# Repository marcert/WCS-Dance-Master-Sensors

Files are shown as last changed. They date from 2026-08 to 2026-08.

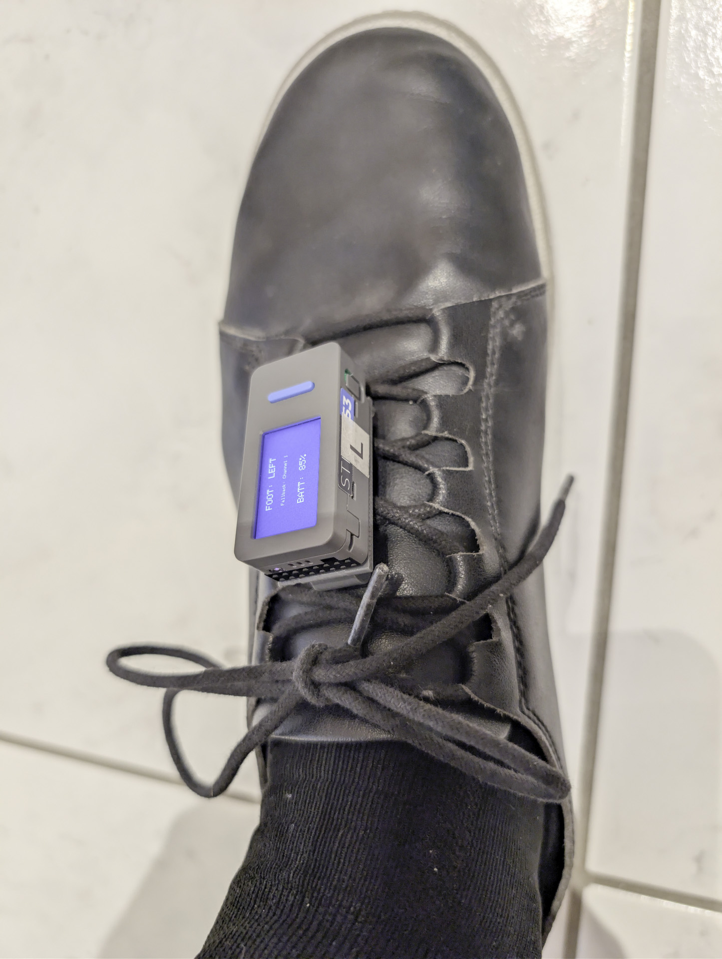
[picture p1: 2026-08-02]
Attachments/Sensor-002.jpg

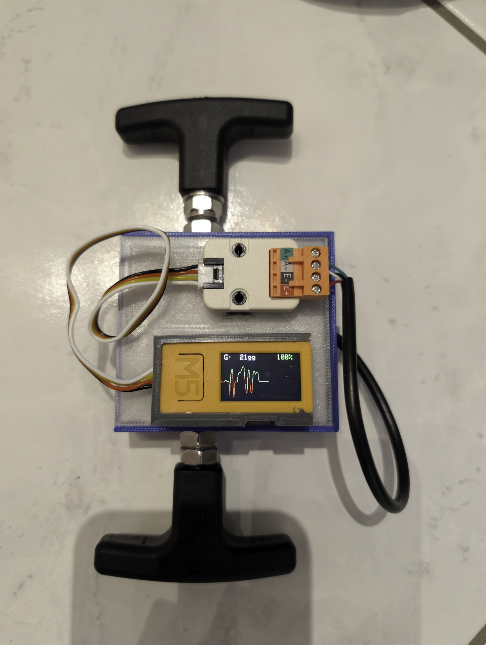
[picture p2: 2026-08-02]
Attachments/Sensor-001.jpg

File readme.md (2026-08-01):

# 🕺 WCS Ultra-Performance Dance & Movement Analysis System

A real-time wireless sensor network and video feedback system built specifically for **West Coast Swing (WCS)** dancers and coaches.

---

## 🎯 Purpose & Goal

Improving connection, timing, and footwork in West Coast Swing often relies on subjective feeling or delayed video review. This system solves that problem by giving **instant physical telemetry and visual feedback** while you dance.

### What it measures in real-time:
* **Footwork & Roll-off Quality (Left & Right Foot):** Measures foot roll-off dynamics via gyroscope angular rate and detects hard impacts / stomping (Z-axis g-force spikes).
* **Connection & Lead/Follow Smoothness (Hand Unit):** Measures pull and push tension in grams via a strain-gauge load cell (-3.5 kg to +3.5 kg) and detects abrupt, harsh movements (jerk index).
* **Live Acoustic & Visual Feedback:** Triggers immediate audio alert tones (e.g., 1000 Hz beep on connection jerk or poor roll-off with heavy impact) and displays synchronized overlay lines directly on a live video feed.

---

## 🚀 Quick Start / How to Use

1. **Power On:** Turn on the **Master Unit** first so it establishes its Wi-Fi channel.
2. **Connect Sensors:** Power on the Foot and Hand sensors. They automatically scan channels (1–13), pair with the Master, and lock onto the channel.
3. **Open Dashboard:** Connect your tablet, phone, or laptop to the Master's Wi-Fi network and open the IP address in any web browser.
4. **Train & Review:**
   * Tap **START CAM** to overlay the telemetry graphs directly over your live camera feed.
   * Use **FREEZE** during or after a pattern to pause graph rendering and analyze connection/footwork spikes frame-by-frame.
   * Press **Button A** on the Hand Unit at any time to tare (zero-out) the weight scale.

---

## 🛠️ Getting Started (Setup & Installation)

### Hardware Requirements
* **1x Master Unit:** M5Stack main unit (M5StickC PLUS / PLUS2 / Core).
* **2x Foot Sensors:** M5Stack units with internal 6-axis IMU.
* **1x Hand Sensor:** M5Stack unit + **HX711** load cell amplifier + Strain-Gauge Load Cell (connected to GPIO 33 DOUT / GPIO 32 SCK).

### Software Requirements
Install the following libraries in Arduino IDE / PlatformIO:
* `M5Unified`
* `WiFi.h` & `esp_wifi.h`
* `esp_now.h`
* `WebServer.h`
* `HX711.h`

### Firmware Flashing
1. **Master Unit:**
   * Create a `secrets.h` file containing your Wi-Fi credentials (`STAMMI_SSID` & `STAMMI_PASS`).
   * Flash the Master code. (If Wi-Fi fails, it falls back to standalone Access Point mode at `192.168.4.1`).
2. **Foot Sensors:**
   * Flash Unit 1 with `#define FOOT_ID 1` (Left Foot).
   * Flash Unit 2 with `#define FOOT_ID 2` (Right Foot).
3. **Hand Sensor:**
   * Flash with `#define HAND_ID 3` (Scale factor default is set to `129.1f`).

---

## 🏗️ System Architecture

```text
                       +-------------------------+
                       |   Foot Sensor (Left)    |
                       | ID: 1 | M5Stack + IMU   |
                       +------------+------------+
                                    |
                                    | (ESP-NOW Broadcast / Channel Auto-Sync)
                                    v
+------------------------+     +----+--------------------+     +-------------------------+
|   Hand / Scale Unit    |---->|   Central Master Unit   |<----|   Foot Sensor (Right)   |
| ID: 3 | HX711 + IMU    |     |    M5Stack Master       |     | ID: 2 | M5Stack + IMU   |
+------------------------+     +----------+--------------+     +-------------------------+
                                          |
                                          | (Wi-Fi AP / STA + WebServer)
                                          v
                              +-----------+--------------+
                              |   Web Dashboard (HTML5)  |
                              | Real-time Canvas Graphs  |
                              | Live Camera Overlay      |
                              +--------------------------+

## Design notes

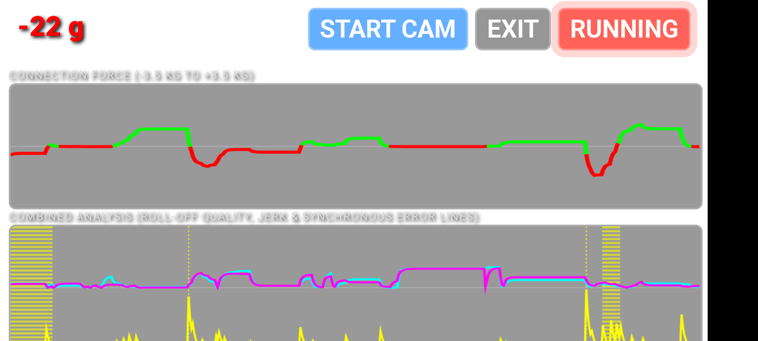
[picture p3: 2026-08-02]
Attachments/screenshot.png

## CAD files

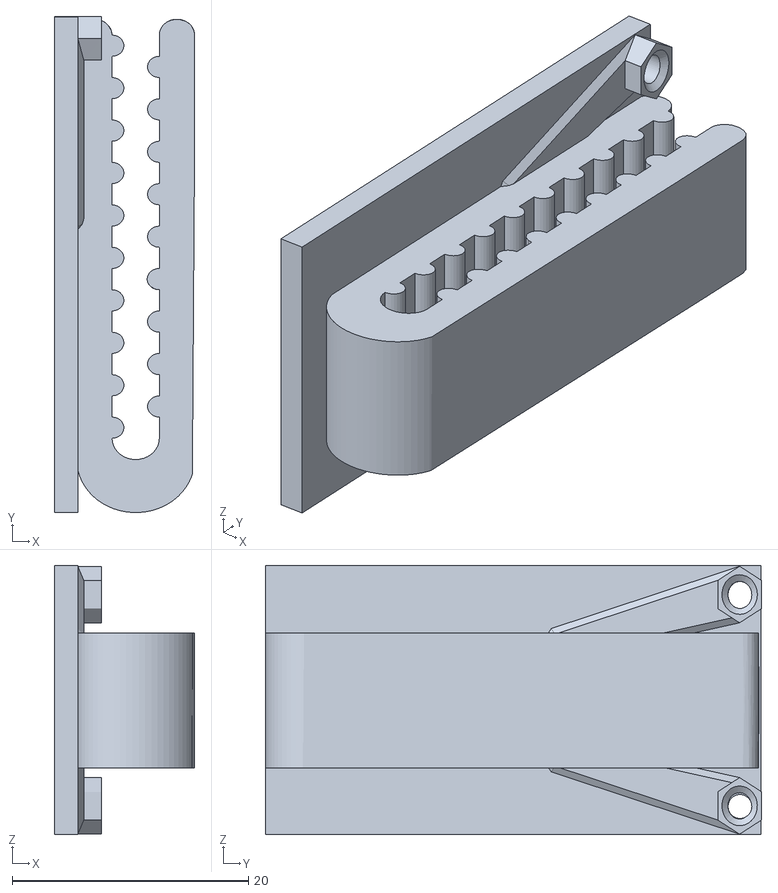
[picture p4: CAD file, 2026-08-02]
Attachments/M5-shoe-mount.stl
11.9 x 42.0 x 22.8

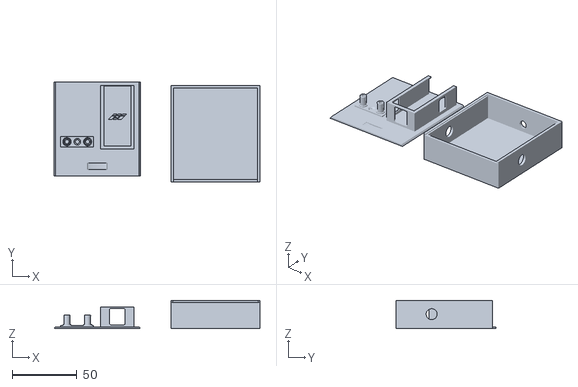
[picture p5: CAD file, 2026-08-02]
Attachments/Scale-box.stl
159.6 x 77.7 x 22.0

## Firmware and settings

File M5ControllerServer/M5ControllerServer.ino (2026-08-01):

#include <M5Unified.h>
#include <esp_now.h>
#include <WiFi.h>
#include <esp_wifi.h>
#include <WebServer.h>
#include "secrets.h"

// --- DATA STRUCTURE FOR FEET (ID 1 & 2) ---
typedef struct struct_imu_data {
  uint8_t foot_id; // 1 = Left, 2 = Right
  float gyro_x;    // Y-rotation from transmitter (roll-off)
  float accel_z;   // Z-acceleration (impact)
} struct_imu_data;

// --- DATA STRUCTURE FOR HAND/SCALE (ID 3) ---
typedef struct struct_hand_data {
  uint8_t hand_id; // 3 = Hand / Scale
  float weight;    // Push/Pull in grams
  float accel_x;
  float accel_y;
  float accel_z;
} struct_hand_data;

// --- DATA STRUCTURE FOR HANDSHAKE / CHANNEL CONFIRMATION ---
typedef struct struct_handshake_ack {
  uint8_t master_channel;
  uint8_t confirmed;
} struct_handshake_ack;

struct_handshake_ack ackPacket;

// --- THRESHOLDS FOR ERROR ALARM (FEET) ---
float GYRO_MIN  = 80.0;   // Degrees/second (minimum roll-off)
float ACCEL_MAX = 1.5;    // g-force (maximum impact)

// Live measurement values
float leftGyro = 0, leftAccel = 0;
float rightGyro = 0, rightAccel = 0;
float handWeight = 0, handAx = 0, handAy = 0, handAz = 0;

// Helper variables for Jerk calculation on M5
float prevHandWeight = 0;
float prevHandAx = 0, prevHandAy = 0, prevHandAz = 1.0;
bool isJerkAlert = false;

// Warning status for visual feedback
enum ErrorState { NONE = 0, ERR_LEFT = 1, ERR_RIGHT = 2, ERR_BOTH = 3 };
volatile ErrorState currentError = NONE;
volatile uint32_t errorStartTime = 0;

// Web server on port 80
WebServer server(80);

// --- HTML DASHBOARD WITH SYNCHRONOUS ERROR LINES ---
const char HTML_PAGE[] PROGMEM = R"rawliteral(
<!DOCTYPE html>
<html lang="en">
<head>
    <meta charset="UTF-8">
    <meta name="viewport" content="width=device-width, initial-scale=1.0, maximum-scale=1.0, user-scalable=no">
    <title>WCS Ultra-Performance Dashboard</title>
    <style>
        body { 
            background: transparent; 
            color: #fff; 
            font-family: 'Arial Black', Gadget, sans-serif; 
            margin: 0; 
            padding: 10px;
            overflow: hidden; 
            box-sizing: border-box;
            height: 100vh;
            display: flex;
            flex-direction: column;
            justify-content: space-between;
            text-shadow: 2px 2px 4px #000; 
        }
        
        #camera-feed {
            position: fixed;
            top: 0;
            left: 0;
            width: 100vw;
            height: 100vh;
            object-fit: cover;
            z-index: -1;
        }

        #header-container {
            display: flex;
            justify-content: space-between;
            align-items: center;
            padding: 0 10px;
            height: 12vh;
        }
        
        #wert { 
            font-size: 8vh; 
            font-weight: 900; 
            line-height: 0.8; 
            margin: 0; 
            padding-bottom: 5px; 
        }
        
        .btn-group {
            display: flex;
            gap: 8px;
            margin: 0; 
            flex-wrap: wrap; 
            justify-content: flex-end;
        }

        .action-btn {
            background-color: rgba(34, 34, 34, 0.6); 
            color: #fff;
            border: 2px solid rgba(255, 255, 255, 0.3);
            padding: 6px 12px;
            font-size: 3.5vw;
            font-family: 'Arial Black', sans-serif;
            font-weight: bold;
            border-radius: 8px;
            cursor: pointer;
            backdrop-filter: blur(4px);
            -webkit-backdrop-filter: blur(4px); 
        }
        
        #cam-btn { background-color: rgba(0, 122, 255, 0.6); }
        #wide-btn { background-color: rgba(0, 200, 120, 0.6); display: none; }
        #full-btn { background-color: rgba(80, 80, 80, 0.6); }

        #debug-info {
            position: fixed;
            bottom: 5px;
            left: 5px;
            right: 5px;
            font-size: 11px;
            font-family: monospace;
            background: rgba(0,0,0,0.8);
            padding: 6px 8px;
            border-radius: 6px;
            max-height: 30vh;
            overflow-y: auto;
            white-space: pre-wrap;
            z-index: 10;
            display: none;
        }

        #freeze-btn.frozen {
            background-color: rgba(255, 59, 48, 0.8);
            animation: pulse 1.5s infinite;
        }
        
        @keyframes pulse {
            0% { box-shadow: 0 0 0 0 rgba(255, 59, 48, 0.6); }
            70% { box-shadow: 0 0 0 12px rgba(255, 59, 48, 0); }
            100% { box-shadow: 0 0 0 0 rgba(255, 59, 48, 0); }
        }

        .graph-container { width: 100%; height: 36vh; display: flex; flex-direction: column; }
        .label { font-size: 13px; color: #ddd; margin-bottom: 2px; text-transform: uppercase; letter-spacing: 1px; }
        
        canvas { 
            background-color: rgba(0, 0, 0, 0.4); 
            border: 2px solid rgba(255, 255, 255, 0.2); 
            width: 100%; 
            height: 100%; 
            display: block; 
            border-radius: 8px; 
        }
        
        .legende { display: flex; gap: 15px; font-size: 11px; margin-top: 4px; color: #ddd; }
        .legende-item { display: flex; align-items: center; gap: 4px; }
        .box-left { width: 12px; height: 12px; background-color: #00ffff; border-radius: 2px; }
        .box-right { width: 12px; height: 12px; background-color: #ff00ff; border-radius: 2px; }
        .box-jerk { width: 12px; height: 12px; background-color: #ffff00; border-radius: 2px; }
        .box-impact { width: 12px; height: 12px; background-color: #ff0000; border-radius: 2px; }
    </style>
</head>
<body>

    <video id="camera-feed" autoplay playsinline></video>

    <div id="header-container">
        <div id="wert">0 g</div>
        <div class="btn-group">
            <button id="cam-btn" class="action-btn" onclick="startCamera()">START CAM</button>
            <button id="full-btn" class="action-btn" onclick="toggleFullscreen()">FULL</button>
            <button id="wide-btn" class="action-btn" onclick="tryUltraWide()">WIDE</button>
            <button id="freeze-btn" class="action-btn" onclick="toggleFreeze()">FREEZE</button>
        </div>
    </div>

    <div id="debug-info"></div>

    <div class="graph-container">
        <div class="label">Connection Force (-3.5 kg to +3.5 kg)</div>
        <canvas id="graph_kraft" width="1000" height="250"></canvas>
    </div>

    <div class="graph-container">
        <div class="label">Combined Analysis (Roll-off Quality, Jerk & Synchronous Error Lines)</div>
        <canvas id="graph_kombi" width="1000" height="250"></canvas>
        <div class="legende">
            <div class="legende-item"><div class="box-left"></div> Sound/Error Left</div>
            <div class="legende-item"><div class="box-right"></div> Sound/Error Right</div>
            <div class="legende-item"><div class="box-jerk"></div> Hand Jerk (Sound 1000 Hz)</div>
        </div>
    </div>

<script>
        // --- FULLSCREEN LOGIC ---
        const fullBtn = document.getElementById('full-btn');
        function toggleFullscreen() {
            if (!document.fullscreenElement && !document.webkitFullscreenElement) {
                if (document.documentElement.requestFullscreen) document.documentElement.requestFullscreen();
                else if (document.documentElement.webkitRequestFullscreen) document.documentElement.webkitRequestFullscreen();
                fullBtn.innerText = "EXIT";
            } else {
                if (document.exitFullscreen) document.exitFullscreen();
                else if (document.webkitExitFullscreen) document.webkitExitFullscreen();
                fullBtn.innerText = "FULL";
            }
        }

        // --- CAMERA LOGIC ---
        const videoElement = document.getElementById('camera-feed');
        const camBtn = document.getElementById('cam-btn');
        const wideBtn = document.getElementById('wide-btn');
        const debugInfo = document.getElementById('debug-info');

        document.getElementById('wert').addEventListener('click', () => {
            debugInfo.style.display = (debugInfo.style.display === 'none' || !debugInfo.style.display) ? 'block' : 'none';
        });

        function updateDebugInfo(stream) {
            const track = stream.getVideoTracks()[0];
            const settings = track.getSettings ? track.getSettings() : {};
            const caps = track.getCapabilities ? track.getCapabilities() : {};

            debugInfo.innerText =
                `Active Lens: ${track.label || 'n/a'}\n` +
                `facingMode: ${settings.facingMode || caps.facingMode || 'n/a'}`;

            if (caps.zoom && caps.zoom.min < 1) wideBtn.style.display = 'block';
            else wideBtn.style.display = 'none';
        }

        async function startCamera() {
            if (navigator.mediaDevices && navigator.mediaDevices.getUserMedia) {
                try {
                    const stream = await navigator.mediaDevices.getUserMedia({ video: { facingMode: "environment" } });
                    videoElement.srcObject = stream;
                    camBtn.style.display = 'none'; 
                    updateDebugInfo(stream);
                } catch (error) { alert("Camera access failed: " + error.message); }
            }
        }

        async function tryUltraWide() {
            if (!videoElement.srcObject) return;
            const track = videoElement.srcObject.getVideoTracks()[0];
            const caps = track.getCapabilities ? track.getCapabilities() : {};

            if (caps.zoom && caps.zoom.min < 1) {
                try {
                    await track.applyConstraints({ advanced: [{ zoom: caps.zoom.min }] });
                    updateDebugInfo(videoElement.srcObject);
                } catch (error) { alert("Wide angle failed: " + error.message); }
            }
        }

        // --- FETCH & GRAPH LOGIC ---
        const canvasKraft = document.getElementById('graph_kraft');
        const ctxKraft = canvasKraft.getContext('2d');
        const canvasKombi = document.getElementById('graph_kombi');
        const ctxKombi = canvasKombi.getContext('2d');
        const wertAnzeige = document.getElementById('wert');
        const freezeBtn = document.getElementById('freeze-btn');
        
        const intervalMs = 20;
        const totalDurationSec = 10;
        const maxPoints = (1000 / intervalMs) * totalDurationSec; // 500 points
        const xStep = canvasKraft.width / maxPoints;               // 2 pixels per step

        let kraftPoints     = new Array(maxPoints).fill(125);
        
        let leftFootPoints  = new Array(maxPoints).fill().map(() => ({ y: 125, isError: false }));
        let rightFootPoints = new Array(maxPoints).fill().map(() => ({ y: 125, isError: false }));
        let jerkPoints      = new Array(maxPoints).fill().map(() => ({ y: 245, isJerkPeak: false }));

        let targetW = 0, targetLG = 0, targetLA = 1, targetRG = 0, targetRA = 1;
        let targetAx = 0, targetAy = 0, targetAz = 1;
        let serverError = 0;
        let serverJerk = false;

        let currentW = 0, currentLG = 0, currentLA = 1, currentRG = 0, currentRA = 1;
        let currentAx = 0.0, currentAy = 0.0, currentAz = 1.0;
        
        let prevAx = 0, prevAy = 0, prevAz = 1;
        let prevWeight = 0;

        let isFrozen = false;

        function toggleFreeze() {
            isFrozen = !isFrozen;
            if (isFrozen) {
                freezeBtn.innerText = "RUNNING";
                freezeBtn.classList.add('frozen');
            } else {
                freezeBtn.innerText = "FREEZE";
                freezeBtn.classList.remove('frozen');
            }
        }

        function fetchSensorData() {
            if (!isFrozen) {
                fetch('/data')
                    .then(response => response.json())
                    .then(data => {
                        targetW  = data.hW;
                        targetLG = data.lG;
                        targetLA = data.lA;
                        targetRG = data.rG;
                        targetRA = data.rA;
                        targetAx = data.hAx;
                        targetAy = data.hAy;
                        targetAz = data.hAz;
                        serverError = data.err;
                        serverJerk  = data.jerk; 
                    })
                    .catch(err => console.log(err));
            }
        }

        setInterval(fetchSensorData, intervalMs);

        setInterval(function() {
            if (isFrozen) return;

            // Smoothing
            currentW  += (targetW - currentW) * 0.4;
            currentLG += (targetLG - currentLG) * 0.4;
            currentLA += (targetLA - currentLA) * 0.4;
            currentRG += (targetRG - currentRG) * 0.4;
            currentRA += (targetRA - currentRA) * 0.4;

            currentAx += (targetAx - currentAx) * 0.4;
            currentAy += (targetAy - currentAy) * 0.4;
            currentAz += (targetAz - currentAz) * 0.4;

            wertAnzeige.innerText = Math.round(targetW) + " g";
            wertAnzeige.style.color = targetW >= 0 ? "#00ff00" : "#ff0000";

            // 1. Force (Scaling adjusted to -3.5 kg to +3.5 kg)
            let y_kraft = 125 - (currentW / 3500) * 125;
            y_kraft = Math.max(0, Math.min(250, y_kraft));
            kraftPoints.shift(); kraftPoints.push(y_kraft);

            // 2. Combined Foot Metric (Roll-off weighted with Impact)
            let leftImpactDev = Math.abs(Math.abs(currentLA) - 1.0);
            let rightImpactDev = Math.abs(Math.abs(currentRA) - 1.0);

            let leftQuality  = Math.abs(currentLG) / (1.0 + leftImpactDev * 2.0);
            let rightQuality = Math.abs(currentRG) / (1.0 + rightImpactDev * 2.0);

            let y_lg = 125 - (leftQuality / 300) * 125;
            let y_rg = 125 - (rightQuality / 300) * 125;

            y_lg = Math.max(0, Math.min(250, y_lg));
            y_rg = Math.max(0, Math.min(250, y_rg));

            let isLeftErr  = (serverError === 1) || (Math.abs(currentLA) > 1.5 && Math.abs(currentLG) < 80.0);
            let isRightErr = (serverError === 2) || (Math.abs(currentRA) > 1.5 && Math.abs(currentRG) < 80.0);

            leftFootPoints.shift();  leftFootPoints.push({ y: y_lg, isError: isLeftErr });
            rightFootPoints.shift(); rightFootPoints.push({ y: y_rg, isError: isRightErr });

            // 3. Lead Smoothness / Jerk
            let dWeight = Math.abs(currentW - prevWeight);
            prevWeight = currentW;

            let dAx = currentAx - prevAx;
            let dAy = currentAy - prevAy;
            let dAz = currentAz - prevAz;
            
            prevAx = currentAx;
            prevAy = currentAy;
            prevAz = currentAz;

            let accelJerk = Math.sqrt(dAx*dAx + dAy*dAy + dAz*dAz);
            let fuehrungshaerteRaw = (dWeight / 50.0) + (accelJerk * 15.0);

            let y_jerk = 245 - (fuehrungshaerteRaw * 8.0); 
            y_jerk = Math.max(5, Math.min(245, y_jerk));
            
            let isJerkPeak = serverJerk || (fuehrungshaerteRaw > 12.0); 
            jerkPoints.shift(); 
            jerkPoints.push({ y: y_jerk, isJerkPeak: isJerkPeak });

        }, intervalMs); 

        function draw() {
            if (!isFrozen) {
                drawKraftGraph();
                drawKombiGraph();
            }
            requestAnimationFrame(draw);
        }
        requestAnimationFrame(draw);

        function drawKraftGraph() {
            ctxKraft.clearRect(0, 0, canvasKraft.width, canvasKraft.height);
            ctxKraft.strokeStyle = 'rgba(255, 255, 255, 0.2)'; 
            ctxKraft.lineWidth = 2;
            ctxKraft.beginPath(); ctxKraft.moveTo(0, 125); ctxKraft.lineTo(canvasKraft.width, 125); ctxKraft.stroke();

            ctxKraft.lineWidth = 6;
            let isGreen = (kraftPoints[0] < 125);
            ctxKraft.beginPath();
            ctxKraft.strokeStyle = isGreen ? '#00ff00' : '#ff0000';
            ctxKraft.moveTo(0, kraftPoints[0]);

            for(let i = 1; i < kraftPoints.length; i++) {
                let x = i * xStep;
                let nextIsGreen = (kraftPoints[i] < 125);
                ctxKraft.lineTo(x, kraftPoints[i]);
                
                if (nextIsGreen !== isGreen) {
                    ctxKraft.stroke();
                    ctxKraft.beginPath();
                    ctxKraft.strokeStyle = nextIsGreen ? '#00ff00' : '#ff0000';
                    ctxKraft.moveTo(x, kraftPoints[i]);
                    isGreen = nextIsGreen;
                }
            }
            ctxKraft.stroke();
        }

        function drawKombiGraph() {
            ctxKombi.clearRect(0, 0, canvasKombi.width, canvasKombi.height);
            
            // Zero line
            ctxKombi.strokeStyle = 'rgba(255, 255, 255, 0.2)';
            ctxKombi.lineWidth = 2;
            ctxKombi.beginPath(); ctxKombi.moveTo(0, 125); ctxKombi.lineTo(canvasKombi.width, 125); ctxKombi.stroke();

            // STEP 1: VERTICAL LINES ON SOUND/ERROR EVENTS (BACKGROUND)
            for (let i = 0; i < maxPoints; i++) {
                let x = i * xStep;
                let leftErr  = leftFootPoints[i].isError;
                let rightErr = rightFootPoints[i].isError;
                let jerkPeak = jerkPoints[i].isJerkPeak;

                if (leftErr || rightErr || jerkPeak) {
                    ctxKombi.beginPath();
                    ctxKombi.setLineDash([]); 

                    if (leftErr && rightErr) {
                        ctxKombi.strokeStyle = '#ff0000'; 
                        ctxKombi.lineWidth = 3;
                    } else if (leftErr) {
                        ctxKombi.strokeStyle = 'rgba(0, 255, 255, 0.9)'; 
                        ctxKombi.lineWidth = 2;
                    } else if (rightErr) {
                        ctxKombi.strokeStyle = 'rgba(255, 0, 255, 0.9)'; 
                        ctxKombi.lineWidth = 2;
                    } else if (jerkPeak) {
                        ctxKombi.strokeStyle = 'rgba(255, 255, 0, 0.6)'; 
                        ctxKombi.setLineDash([4, 4]);
                        ctxKombi.lineWidth = 2;
                    }

                    ctxKombi.moveTo(x, 0);
                    ctxKombi.lineTo(x, canvasKombi.height);
                    ctxKombi.stroke();
                    ctxKombi.setLineDash([]); 
                }
            }

            // STEP 2: DRAW ANALYSIS CURVES ON TOP
            ctxKombi.lineWidth = 4;
            ctxKombi.strokeStyle = '#00ffff';
            ctxKombi.beginPath();
            ctxKombi.moveTo(0, leftFootPoints[0].y);
            for(let i = 1; i < leftFootPoints.length; i++) { ctxKombi.lineTo(i * xStep, leftFootPoints[i].y); }
            ctxKombi.stroke();

            ctxKombi.lineWidth = 4;
            ctxKombi.strokeStyle = '#ff00ff';
            ctxKombi.beginPath();
            ctxKombi.moveTo(0, rightFootPoints[0].y);
            for(let i = 1; i < rightFootPoints.length; i++) { ctxKombi.lineTo(i * xStep, rightFootPoints[i].y); }
            ctxKombi.stroke();

            ctxKombi.lineWidth = 3;
            ctxKombi.strokeStyle = '#ffff00';
            ctxKombi.beginPath();
            ctxKombi.moveTo(0, jerkPoints[0].y);
            for(let i = 1; i < jerkPoints.length; i++) { ctxKombi.lineTo(i * xStep, jerkPoints[i].y); }
            ctxKombi.stroke();
        }
    </script>
</body>
</html>
)rawliteral";

// Web server Endpoint: Send JSON data
void handleData() {
  String json = "{";
  json += "\"lG\":" + String(leftGyro) + ",";
  json += "\"lA\":" + String(leftAccel) + ",";
  json += "\"rG\":" + String(rightGyro) + ",";
  json += "\"rA\":" + String(rightAccel) + ",";
  json += "\"hW\":" + String(handWeight) + ",";
  json += "\"hAx\":" + String(handAx) + ",";
  json += "\"hAy\":" + String(handAy) + ",";
  json += "\"hAz\":" + String(handAz) + ",";
  json += "\"err\":" + String((int)currentError) + ",";
  json += "\"jerk\":" + String(isJerkAlert ? "true" : "false");
  json += "}";
  server.send(200, "application/json", json);
}
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
void loop() {
  M5.update();
  server.handleClient();

  if (M5.BtnB.wasHold()) {
    M5.Display.fillScreen(BLACK);
    M5.Display.setTextColor(WHITE, BLACK);
    M5.Display.setTextSize(2);
    M5.Display.drawString("OFF...", M5.Display.width() / 2, M5.Display.height() / 2);
    delay(500);
    M5.Power.powerOff();
  }

  if (currentError != NONE && (millis() - errorStartTime > 200)) {
    currentError = NONE;
  }

  uint16_t leftBg  = (currentError == ERR_LEFT)  ? RED : BLACK;
  uint16_t rightBg = (currentError == ERR_RIGHT) ? RED : BLACK;

  uint16_t leftFg  = (currentError == ERR_LEFT)  ? WHITE : BLUE;
  uint16_t rightFg = (currentError == ERR_RIGHT) ? WHITE : RED;

  int batLevel = M5.Power.getBatteryLevel();

  M5.Display.setTextSize(2);

  M5.Display.setCursor(5, 5);
  M5.Display.setTextColor(leftFg, leftBg);
  M5.Display.printf("L: G:%4.0f A:%3.1f ", leftGyro, leftAccel);

  M5.Display.setCursor(5, 30);
  M5.Display.setTextColor(rightFg, rightBg);
  M5.Display.printf("R: G:%4.0f A:%3.1f ", rightGyro, rightAccel);

  M5.Display.setCursor(5, 55);
  M5.Display.setTextColor(GREEN, BLACK);
  M5.Display.printf("H: %4.0f g        ", handWeight);

  M5.Display.setCursor(5, 80);
  M5.Display.setTextColor(YELLOW, BLACK);
  M5.Display.printf("BAT: %3d%%       ", batLevel);

  delay(20);
}

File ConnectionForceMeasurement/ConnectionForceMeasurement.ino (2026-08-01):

#include <M5Unified.h>
#include <esp_now.h>
#include <WiFi.h>
#include <esp_wifi.h>
#include "HX711.h" // Bibliothek für die Kraftmessdose (Unit Weight)

// --- PINS FÜR DEINE KRAFTMESSDOSE (UNIT WEIGHT) ---
#define HX711_DOUT_PIN 33
#define HX711_SCK_PIN  32

// Neuer korrigierter Faktor:
#define SCALE_FACTOR 129.1f

// --- ESP-NOW DATENSTRUKTUR SENDE-PAKET (HAND / WAAGE) ---
typedef struct struct_hand_data {
  uint8_t hand_id; // Immer 3 für Hand
  float weight;    // Zug/Druck in Gramm/kg
  float accel_x;   // Beschleunigung X
  float accel_y;   // Beschleunigung Y
  float accel_z;   // Beschleunigung Z
} struct_hand_data;

// --- DATENSTRUKTUR EMPFANGS-PAKET (HANDSHAKE ACK VOM MASTER) ---
typedef struct struct_handshake_ack {
  uint8_t master_channel;
  uint8_t confirmed;
} struct_handshake_ack;

struct_hand_data sendData;
esp_now_peer_info_t peerInfo;

uint8_t broadcastAddress[] = {0xFF, 0xFF, 0xFF, 0xFF, 0xFF, 0xFF};

// Status-Variablen für Handshake
volatile bool masterAckReceived = false;
volatile uint8_t masterConfirmedChannel = 0;

// HX711 Objekt
HX711 scale;

// Globale Variablen für das Display-Diagramm
int graphX = 0;
int lastY = 80;

// Variablen zur Erkennung von Wertänderungen
float lastSentWeight = -9999.0f;
float lastSentAx = 0.0f, lastSentAy = 0.0f, lastSentAz = 0.0f;
uint32_t lastSendTime = 0;

// Timer für Akku-Anzeige
uint32_t lastBatCheck = 0;

// --- ESP-NOW EMPFANGS-CALLBACK FÜR HANDSHAKE ACK VOM MASTER ---
#if defined(ESP_ARDUINO_VERSION_MAJOR) && ESP_ARDUINO_VERSION_MAJOR >= 3
void OnDataRecv(const esp_now_recv_info_t *recv_info, const uint8_t *data, int len) {
#else
void OnDataRecv(const uint8_t *mac_addr, const uint8_t *data, int len) {
#endif
  if (len == sizeof(struct_handshake_ack)) {
    struct_handshake_ack ack;
    memcpy(&ack, data, sizeof(ack));
    if (ack.confirmed == 1) {
      masterConfirmedChannel = ack.master_channel;
      masterAckReceived = true;
    }
  }
}

void setup() {
  // 1. CPU-Frequenz senken (Spart massiv Akku, 80MHz reicht völlig aus)
  setCpuFrequencyMhz(80);

  auto cfg = M5.config();
  cfg.internal_imu = true; // IMU aktivieren
  M5.begin(cfg);

  // --- DISPLAY SETUP ---
  M5.Display.setRotation(3);
  M5.Display.fillScreen(BLACK);
  M5.Display.setTextSize(2);
  M5.Display.setTextColor(WHITE, BLACK);
  M5.Display.drawString("INIT WEIGHT...", 10, 5);

  // --- KRAFTMESSDOSE (HX711) SETUP ---
  scale.begin(HX711_DOUT_PIN, HX711_SCK_PIN);
  scale.set_scale(SCALE_FACTOR);
  delay(1000);
  scale.tare(); // Automatischen Nullpunkt beim Start setzen

  // --- ESP-NOW & WIFI SETUP ---
  WiFi.mode(WIFI_STA);
  WiFi.disconnect();

  // 2. Sendeleistung auf 11 dBm reduzieren (3-5m Reichweite, spart Strom)
  WiFi.setTxPower(WIFI_POWER_11dBm);

  if (esp_now_init() != ESP_OK) {
    M5.Display.drawString("ESP-NOW ERR", 10, 5);
    return;
  }

  // Receive-Callback registrieren für den Master-Scan
  esp_now_register_recv_cb(OnDataRecv);

  // --- AUTOMATISCHER KANAL-SUCHLAUF (KANAL 1 BIS 13) ---
  M5.Display.fillScreen(BLACK);
  M5.Display.drawString("Suche Master...", 10, 5);

  memcpy(peerInfo.peer_addr, broadcastAddress, 6);
  peerInfo.encrypt = false;

  sendData.hand_id = 3; // ID 3 für die Hand/Waage
  sendData.weight  = 0.0f;
  sendData.accel_x = 0.0f;
  sendData.accel_y = 0.0f;
  sendData.accel_z = 1.0f;

  uint8_t foundChannel = 0;

  for (uint8_t ch = 1; ch <= 13; ch++) {
    esp_wifi_set_promiscuous(true);
    esp_wifi_set_channel(ch, WIFI_SECOND_CHAN_NONE);
    esp_wifi_set_promiscuous(false);
    
    peerInfo.channel = ch;

    if (esp_now_is_peer_exist(broadcastAddress)) {
      esp_now_del_peer(broadcastAddress);
    }
    esp_now_add_peer(&peerInfo);

    delay(10); // Einschwingzeit für das Wi-Fi-Radio

    for (int attempt = 0; attempt < 3; attempt++) {
      masterAckReceived = false;
      esp_now_send(broadcastAddress, (uint8_t *)&sendData, sizeof(sendData));

      uint32_t startWait = millis();
      while (millis() - startWait < 30) { // 30 ms auf Antwortpaket vom Master warten
        if (masterAckReceived) {
          foundChannel = (masterConfirmedChannel > 0) ? masterConfirmedChannel : ch;
          break;
        }
        delay(1);
      }
      if (foundChannel > 0) break;
      delay(5);
    }

    if (foundChannel > 0) break;
  }

  // --- KANAL-ERGEBNIS FIXIEREN ---
  M5.Display.fillScreen(BLACK);
  M5.Display.setTextSize(2);
  M5.Display.setTextColor(WHITE, BLACK);

  if (foundChannel > 0) {
    esp_wifi_set_promiscuous(true);
    esp_wifi_set_channel(foundChannel, WIFI_SECOND_CHAN_NONE);
    esp_wifi_set_promiscuous(false);

    peerInfo.channel = foundChannel;
    if (esp_now_is_peer_exist(broadcastAddress)) {
      esp_now_del_peer(broadcastAddress);
    }
    esp_now_add_peer(&peerInfo);

    M5.Display.printf("Ch %d OK!", foundChannel);
  } else {
    // Fallback auf Kanal 1
    esp_wifi_set_promiscuous(true);
    esp_wifi_set_channel(1, WIFI_SECOND_CHAN_NONE);
    esp_wifi_set_promiscuous(false);

    peerInfo.channel = 1;
    if (esp_now_is_peer_exist(broadcastAddress)) {
      esp_now_del_peer(broadcastAddress);
    }
    esp_now_add_peer(&peerInfo);
    
    M5.Display.drawString("Fallback Ch 1", 10, 5);
  }

  delay(1000);
  M5.Display.fillScreen(BLACK);
}

void drawGraph(float weight) {
  // Mapping von -2500g (-2,5kg) bis +2500g (+2,5kg) auf Y-Pixel (130 bis 30)
  int newY = map((long)weight, -2500, 2500, 130, 30);
  newY = constrain(newY, 30, 130);

  // Zug (Grün) / Druck (Rot)
  uint16_t color = (weight > 0) ? GREEN : RED;

  M5.Display.drawLine(graphX, lastY, graphX + 1, newY, color);
  
  graphX++;
  lastY = newY;

  // Wenn der Bildrand erreicht ist: Bereich löschen und neu anfangen
  if (graphX > 235) {
    M5.Display.fillRect(0, 30, 240, 105, BLACK);
    graphX = 0;
  }
}
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

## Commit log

2026-08-02 3d print files added
2026-08-02 files added
    [M5-shoe-mount.stl, Scale-box.stl]
2026-08-11 performance improved, battery consumption reduced and Metrics slightly updated
2026-08-14 Pelvic Sensor added with first metrics. Documentation added
2026-08-15 Pelvic Sensor added, new metrics introduced, documentation updated
2026-08-21 new metrics added and doumented (Hip-Foot-Coupling, Bounce, Pelvic Tilt)
2026-08-24 Tempo-adaptive step trigger threshold added, preJerk >2.0 gate on aZ path, Phantom filter threshold raised to 0.90 g, Battery display fix, Screenshot placeholders, Documentation cleaned up
2026-08-25 Fix Ball→Heel algorithm; recalibrate SLUGGISH and ASYMMETRIC thresholds
    Ball→Heel: the previous earlyMean was computed from post-reset CF samples
    (always ≈0° after impact reset), causing 100% false BALL ONLY results.
    Fix stores θ at trigger time (T-1 snapshot, pre-reset) as anchorThetaAtTrigger
    and uses lateMean (second-half post-reset samples) to detect settled foot angle.
    Conditions simplified: BALL→HEEL ✓ requires θ_T-1 < -2° and lateMean > 3°.
    SLUGGISH threshold raised 38% → 52%: WCS Grounding (40–52% double stance)
    is correct technique, not a fault. Verified against video: 0 false alarms at 52%.
    ASYMMETRIC threshold raised 25% → 35%: ASI reacted to direction-chang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
2026-08-25 Fix Anchor Settle always-MEASURING; lower soft-anchor step threshold; UI badge nowrap
    Anchor Settle algorithm rework:
    - Start fresh on first BACKWARD step, extend deadline on each subsequent one (lastTrigger approach)
    - Force evaluate on first non-BACKWARD step (Beat 3) instead of waiting for 500ms timer
    - Score holds visible for 2000ms to prevent immediate reset by next phrase's backward walk
    - Decoupled anchorSettleWindowMs (500ms fixed) from anchorWindowMs (Ball→Heel, 280–900ms tempo-adaptive)
    - Same fix applied to partner dashboard (index.h)
    Soft-anchor step detection:
    - Lower aZThr at slow practice tempo (>800ms/step): 0.95g → 0.92g to catch gentle ball-landings
    - Validated: 26/2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
2026-08-26 Fix Anchor Settle: survive sensor dropouts, correct window gating, faster warmup
    - Move timer evaluation outside pelvicOk block so brief sensor dropouts
    no longer kill the evaluation window mid-phrase
    - Remove pelvicOk gate from backward-step trigger (window opens on any
    backward step regardless of pelvis sensor state)
    - lastTrigger extended only for bwd ≤ 2 (triple beats 5 & 6); subsequent
    backward steps no longer reopen the window across phrases
    - AMBIGUOUS extension capped at bwd < 2 to prevent &6 from delaying score
    - Evaluation threshold: bwdCount ≥ 1 (beat 6 lands in AMBIGUOUS zone at
    practice tempo, bwd rarely reaches 2)
    - Minimum samples lowered: n ≥ 3 (pelvis sensor tr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
2026-08-26 Screenshot with camera and all tiles
2026-08-27 Add solo/partner use-case intro to all three README files
    Root readme.md and both doc-folder READMEs now mention both dashboards
    in the intro paragraph with direct links, so readers land on the right
    guide immediately without having to scan the document table.
2026-08-27 Fix force range: 3.5 kg → 4.0 kg in readme and explanations docs
    Code uses divisor 4000 g (index.h:555) and labels ±4.0 kg since the
    graph scale was raised; readme and both explanations.md files still
    referenced the old 3.5 kg figure.
2026-08-27 Sync screenshot images between EN and DE dancer_guide_solo
    EN had text placeholders where DE already had real images (scr.jpg,
    Buttons.jpg). Replaced both EN placeholders with the same image blocks.
    Also fixed missing blank line before heading in DE file.
2026-08-27 Fix three wrong values in solo_explanations docs (EN+DE)
    WRONG-1 (both): aZ step trigger thresholds were 0.95/0.97 g —
    code uses 0.92 g (slow, >800 ms) and 0.95 g (dance tempo).
    Fixed in 3 places each (T-1 description, formula, cross-foot lockout note).
    WRONG-2 (DE only): HEEL SLAM / TOE JAM / HARD IMPACT badge table
    showed 30 g/s — code threshold is 88 internal = 22 g/s displayed.
    (30 g/s is the separate impact-click and bar-full-scale threshold, not SLAM.)
    WRONG-3 (DE only): Delay Ramp settlement condition was 0.08 g / 15 °/s —
    code uses 0.15 g and 40 °/s.
2026-08-27 Add Grounding Card (ADV), fix badges, update all docs with SLAPPING analysis
    solo.h:
    - Grounding Card (ADV only): SDR + SETTLE badges with pelvicOk gate,
    GND score + progress bar (SDR 40%, SETTLE 30%, ROLL 30%)
    - ROLL badge (rollSmoothBadge) moved to Step Card, all levels
    - Fix: wrap grounding triggers in if(triggerImpact) — was firing every frame
    - Fix: clear inline style on SDR/SETTLE badges so badge-green/yellow/red renders
    - Remove HITCH badge + state machine logic
    - Remove strike angle display (-1°) and jerk bar
    - Remove LSI/SMOOTH metric from grounding card
    - Remove pelvicRaw debug line from pelvis card
    - Direction badges: FWD/BWD (already in docs)
    Docs (EN + DE solo_explanations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
2026-08-27 Add Grounding-only-in-Solo note to partner guide (EN+DE)
2026-08-28 Fix direction badge text FWD/BWD in dancer guides (EN+DE)
    Replace outdated FORWARD/BACK badge labels with current ➡ FWD / ⬅ BWD
    throughout all dancer_guide_solo section headers, tables, and callouts.
2026-08-31 Remove training prompts from repo (moved outside repo)
    Training prompt files are personal coaching material, not part of
    the firmware/documentation codebase. Moved to Training_Prompts/
    alongside the repo directory.
2026-09-28 Recalibrate partner dashboard for connection-force artifacts; fix beginner view; sync all docs
    Partner dashboard (index.h) — validated video where
    connection force contaminated foot/pelvis signals:
    - Force graph rescaled ±5 kg -> ±10 kg (peaks clipped above 6 kg)
    - Impact jerk threshold 22 -> 34 g/s, with a connection-force gate (x1.8 above
    2 kg, hard-capped at 50 g/s) so genuine hard stomps still fire
    - BOUNCY aZVar 0.020 -> 0.038; ANCHORED score >=60 -> >=42
    - Hip Activation ACTIVE 60 -> 45 deg/s
    - LATERAL SWAY downgraded to SLIGHT SWAY when |force| > 1.5 kg
    - DELAY badge forced to DELAYED when |force| > 1.5 kg (push/pull both distort it)
    - Anchor Settle window ported to tempo-adapti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
2026-09-29 Dancer-language pass: solo guides EN + DE
    - Replace "Jerk" column (g/s) in step badge tables with plain "Impact"
    descriptor (light / hard / very light / moderate)
    - Remove % thresholds from DELAY, Double Stance, Roll-off Symmetry,
    Follower mode tables; use qualitative descriptions
    - Remove ms values from Anchor Settle, Hip Settle, SETTLE badge prose;
    use "shortly after" / "measurement window"
    - Remove g threshold from Hip Settle footnote header
    - "200 ms" in BRUSH+HEEL → "shortly after"
    - "100 ms / 40–100 ms" in Hip-Foot Coupling → plain language
    - Remove GND Score numeric bar thresholds (≥ 65 / 35–64 / < 35)
    - ASI% → Side Symmetry (ASI) with plain green target description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
2026-09-29 Add Solo Quickstart guide (EN + DE) with entry-point links
    New beginner-focused quickstart that gets a dancer running in ~60 seconds,
    kept deliberately short since beginners want to start, not read:
    - Chapter 1 (Beginner): 4-step setup, single goal (soft landing, heel/toe
    first), one card to watch, and a fix-it table for the common mistakes
    - Chapter 2 (near-Intermediate): switch to INT and aim for CLEAN ROLL /
    OPTIMAL ROLL / DELAYED ✓, then hands off to the full guide
    New files:
    - Documentation_english/quickstart_solo.md
    - Documentation_german/quickstart_solo.md
    Linked from every solo entry point (EN + DE):
    - top of both dancer_guide_solo.md
    - both Documentation README.md (callout +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
2026-09-29 Add optional thorax sensor (ID 5): upper-body poise + partner frame-coupling
    New fifth optional sensor node measuring upper-body poise, plus a
    no-extra-hardware connection-coupling metric on the partner dashboard.
    - M5Thorax/: new firmware node (clone of M5Pelvic, SENSOR_ID 5), worn C7-T1
    - Master: receive/aggregate ID 5, expose tG/tA/tAy/tYaw/tAx/tOk/tBatt in /data;
    combine both feet onto one status line (F: left then right) and restore the
    master-battery row
    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
2026-09-30 Calibrate thorax poise from video priors; symmetric bands + dance-stance ZERO
    Refines the thorax poise metrics after the first hardware test and two Gemini
    video analyses of advanced/all-star dancers:
    - Fix sagittal sign for USB/connector-down mounting (forward lean -> positive)
    - Set thresholds from consolidated video priors, loosened slightly for
    non-expert users: Poise green |s|<=7 / red >±13, Level red >11°, Stack
    asymmetric (pike +7/+12, opening -5/-10)
    - Make Poise symmetric and document that ZERO is pressed in the natural
    dance-ready stance (one ZERO serves feet, pelvis & thorax) - consistent with
    the symmetric pelvic-tilt metric; not upright-then-lean
    - Make Top-Line Quiet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
2026-10-07 Fix solo dashboard overflow when pelvis+thorax active (ADV landscape)
    With all sensors online the Core (Pelvis & Torso) card holds ~14 rows,
    which overflowed the half-height grid cell and clipped the bottom cards
    (and the lower torso rows). The earlier stopgap shrank the Core badges to
    0.56rem, making them unreadable next to the other cards.
    Rework the ADV landscape grid (gated by a new `core-online` class toggled
    from JS when pelvis and/or thorax come online):
    - Core spans the full left column over the top two rows at normal,
    readable badge size; vertical rhythm tightened via zero margins +
    line-height only (no font shrink).
    - Double Stance and ASI stack in the right column's top two r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
2026-10-29 Add mental-cue callouts to solo and partner dancer guides
    Solo guide: a "rolling through the feet" cue block in the ROLL badge
    section — don't over-reach the strike, brake the landing with the legs,
    settle balance before committing weight, guide the foot in rather than
    plant it; ties SLAPPING / HARD IMPACT to CLEAN ROLL and SMOOTH LOAD.
    Partner guide: a "holding the frame" cue block in the Frame badge
    section — shoulder in its home position, upper back engaged, centre and
    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
